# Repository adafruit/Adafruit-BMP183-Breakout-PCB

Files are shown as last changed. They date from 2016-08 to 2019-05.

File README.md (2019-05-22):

## Adafruit BMP183 Breakout PCB (Discontinued)
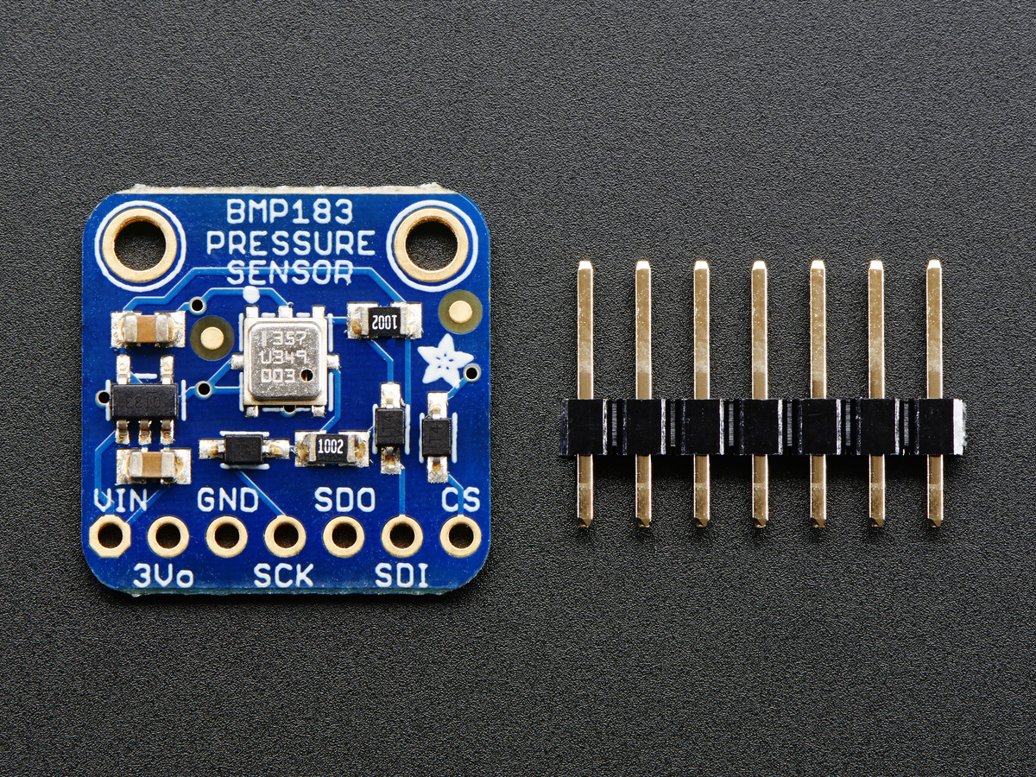
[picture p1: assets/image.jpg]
<a href="http://www.adafruit.com/products/1900"><br/>
Click here to view in the Adafruit shop</a>

Fans of the BMP085/BMP180 will want to take a look at the new BMP183 - an SPI spin on the old familiar classic. This precision sensor from Bosch is the best low-cost sensing solution for measuring barometric pressure and temperature. Because pressure changes with altitude you can also use it as an altimeter!

PCB files for the Adafruit BMP183 Breakout (discontinued). The format is EagleCAD schematic and board layout
- https://www.adafruit.com/product/1900

### License

Adafruit invests time and resources providing this open source design, please support Adafruit and open-source hardware by purchasing products from [Adafruit](https://www.adafruit.com)!

All text above must be included in any redistribution

Designed by Limor Fried/Ladyada for Adafruit Industries.
Creative Commons Attribution/Share-Alike, all text above must be included in any redistribution. 
See license.txt for additional information.

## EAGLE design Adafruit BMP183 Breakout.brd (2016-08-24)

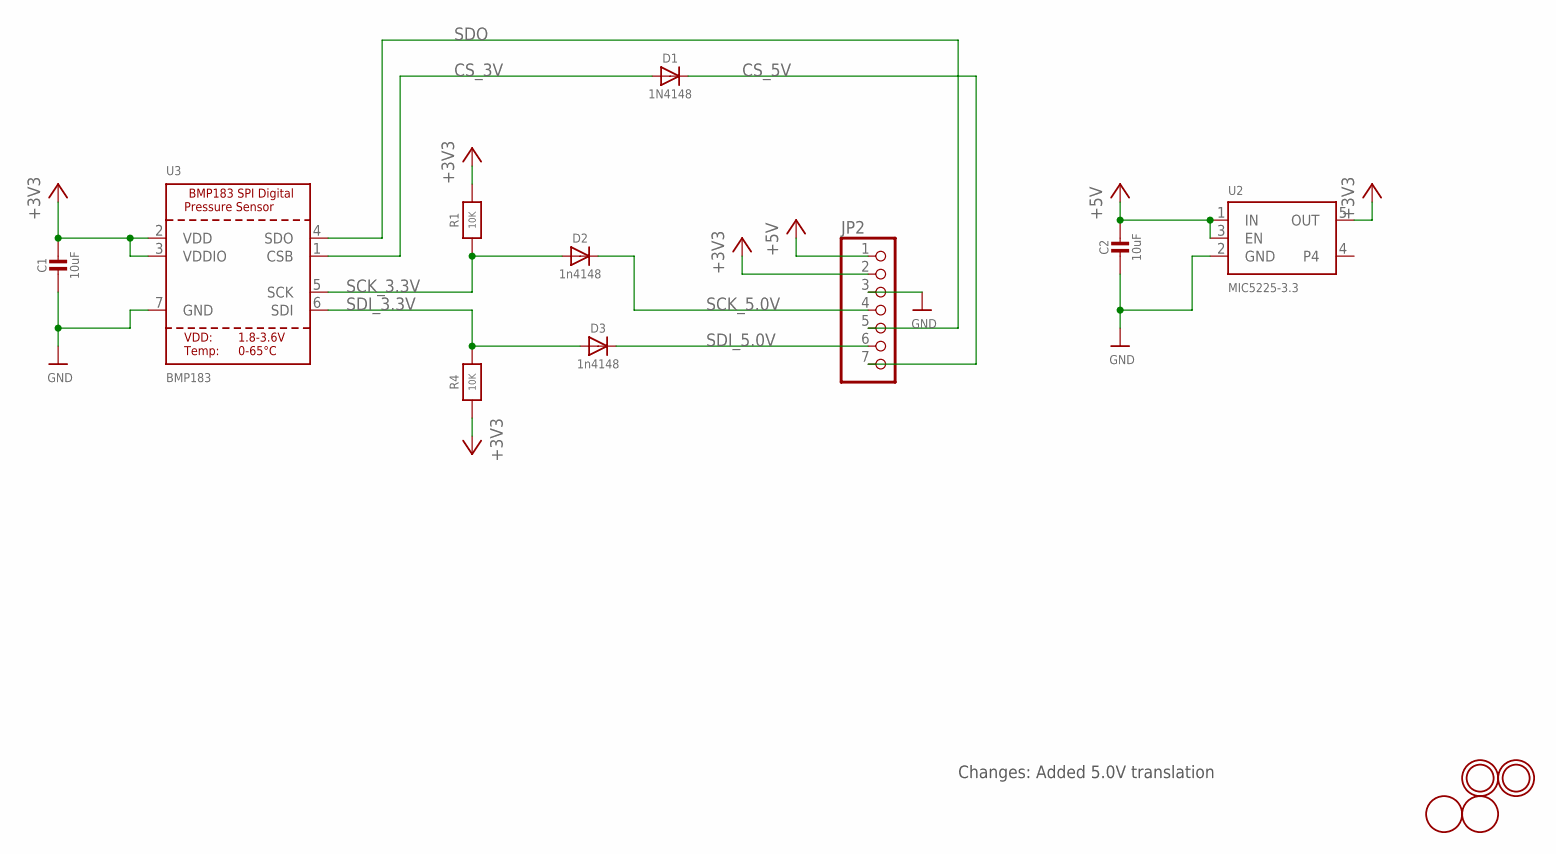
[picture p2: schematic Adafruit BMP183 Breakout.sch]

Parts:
C1, C2: 10uF; 0805-NO
D1: 1N4148; SOD-323
D2, D3: 1n4148; SOD-323
JP2: HEADER-1X770MIL; 1X07_ROUND_70
R1, R4: 10K; 0805-NO
U2: MIC5225-3.3; SOT23-5
U3: BMP183; BMP18X_EXTENDED
U$5, U$15: FIDUCIAL; FIDUCIAL_1MM
U$7, U$8: MOUNTINGHOLE2.0; MOUNTINGHOLE_2.0_PLATED

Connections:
+3V3: C1.1, JP2.2, R1.2, R4.1, U2.5 (OUT), U3.2 (VDD), U3.3 (VDDIO)
+5V: C2.1, JP2.1, U2.1 (IN), U2.3 (EN)
CS_3V: D1.A, U3.1 (CSB)
CS_5V: D1.C, JP2.7
GND: C1.2, C2.2, JP2.3, U2.2 (GND), U3.7 (GND)
SCK_3.3V: D2.A, R1.1, U3.5 (SCK)
SCK_5.0V: D2.C, JP2.4
SDI_3.3V: D3.A, R4.2, U3.6 (SDI)
SDI_5.0V: D3.C, JP2.6
SDO: JP2.5, U3.4 (SDO)

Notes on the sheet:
Changes: Added 5.0V translation

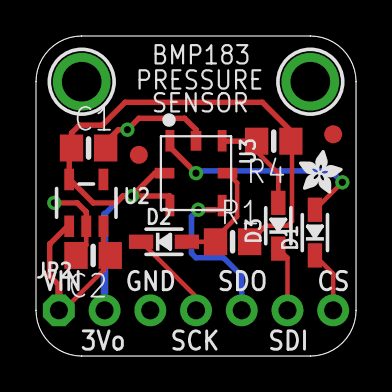
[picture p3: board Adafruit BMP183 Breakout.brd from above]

Board: 2 copper layers, 17.8 x 17.8 mm, 16 parts (1 on the bottom side), 10 nets.

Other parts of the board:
U$2, U$6: ADAFRUIT_2.5MM
